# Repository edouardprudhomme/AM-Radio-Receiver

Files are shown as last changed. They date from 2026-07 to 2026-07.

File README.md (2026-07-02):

# AM Radio Receiver




A fully functional, custom-built AM Radio Receiver designed from scratch on a breadboard. This project blends electronic design with electromagnetic field theory to successfully capture local AM broadcasting frequencies (540 kHz to 1600 kHz). 

Designed with a special **Montreal Canadiens (Bleu, Blanc, Rouge)** theme, the ultimate goal of this build was to achieve a clean signal at **TSN 690 kHz** to listen to live hockey broadcasts.

## 👥 The Team
* Edouard Prud'Homme
* Frédéric Pimentel

## 🎥 Video Explanation and Demonstration
*(https://www.youtube.com/watch?v=ummKtrk6xlA)* (in french)

## 🧠 Theoretical Operation (The 4 Stages)
1. **Reception (Faraday's Law):** A custom 40x40 cm wooden loop antenna captures variations in the ambient magnetic field, inducing an electromotive force.
2. **Tuning / Filtering (LC Circuit):** A parallel LC tank circuit isolates the target frequency. 
3. **Demodulation (Envelope Detector):** A Germanium diode with a low forward voltage drop rectifies the weak AM signal, stripping the high-frequency carrier wave.
4. **Amplification:** An LM386 audio amplifier IC boosts the isolated audio signal to drive standard headphones.

## 📐 Design Choices & Engineering Math
To hit our target of **TSN 690 kHz** reliably, we had to work within the strict constraint of our variable capacitor, which had a limited range of **10 pF to 100 pF**. 

* **Antenna Geometry:** We constructed a 40cm x 40cm wooden frame using brass screws (to avoid magnetic interference).
* **Inductance ($L$):** Winding exactly 20 turns of copper wire yielded a measured inductance of **~870 µH**.
* **Capacitance ($C$):** Using the resonance formula $f = \frac{1}{2\pi\sqrt{LC}}$, targeting 690 kHz required a capacitance of exactly **61 pF**. 

This brilliant mathematical alignment placed our target frequency directly in the center of our variable capacitor's range, allowing for highly stable and accurate tuning.

## 🛠️ Hardware & Tools
* **Antenna:** Custom wooden frame (40x40cm), 20 turns of copper wire, brass screws.
* **Tuning:** 10-100 pF Variable tuning capacitor.
* **Demodulation:** Germanium Diode.
* **Amplification:** LM386 Audio Amplifier IC.
* **Schematics:** Designed in [KiCad](https://www.kicad.org/).

## 📁 Repository Contents
* `/Hardware` - Contains the KiCad schematic (`.sch`) and project files.

## 🚀 How to Replicate
1. Open the `.sch` file in KiCad to view the complete wiring diagram.
2. Ensure the middle pin (rotor) of the variable capacitor is wired to common ground to eliminate "hand capacitance" interference while tuning.
3. Keep the breadboard wires as short as possible to reduce parasitic capacitance, which severely limits high-frequency reception (like CJAD 800 kHz).

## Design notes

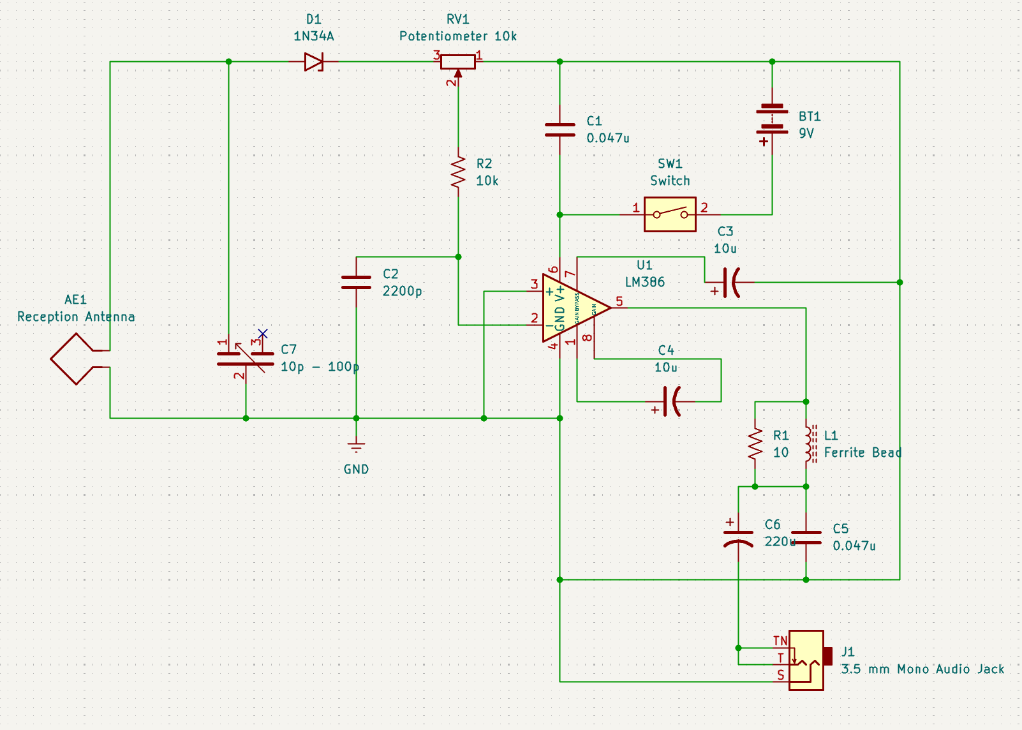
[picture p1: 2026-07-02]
Hardware/radio_schematic.png

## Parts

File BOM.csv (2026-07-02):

Reference | Quantity | Component | Description_Value | Notes
ANT1 | 1 | Cadre en bois | 40 cm x 40 cm | Structure pour la bobine de l'antenne
ANT2 | 1 | Fil verni | AWG 26 | Pour générer l'inductance de ~870 µH
ANT3 | 1 | Vis en laiton | Lot | Matériel de fixation non magnétique
C1 | 1 | Condensateur variable | 10 pF - 100 pF | Tuning pour le circuit LC (remplacement du modèle maison)
D1 | 1 | Diode au germanium | 1N34A | Détecteur d'enveloppe (démodulation)
U1 | 1 | Amplificateur opérationnel | LM386 | Amplificateur de puissance
R1 | 1 | Potentiomètre rotatif | 10 kΩ | Contrôle du volume
R2 | 1 | Résistance | 10 Ω | Filtre anti-oscillation
R3 | 1 | Résistance | 10 kΩ | Polarisation de l'ampli-op
C2 | 1 | Condensateur électrolytique | 220 µF | Couplage de sortie vers les écouteurs
C3 | 2 | Condensateur électrolytique | 10 µF | Gain de l'ampli-op et découplage
C4 | 2 | Condensateur en céramique | 0.047 µF | Filtre anti-oscillation et découplage
C5 | 1 | Condensateur en céramique | 2200 pF | Filtrage RF
L1 | 1 | Perle en ferrite | 998 Ω @ 100 MHz | Filtrage des hautes fréquences
SW1 | 1 | Interrupteur à glissière | 2 positions | On/Off du circuit
CON1 | 1 | Connecteur pour batterie | 9V | Alimentation
J1 | 1 | Prise audio stéréo | 3.5 mm | Sortie pour les écouteurs
BRD1 | 1 | Platine d'expérimentation | 4.5 x 3.5 cm | Base du prototype
WIR1 | 1 | Câbles de connexion | Ensemble de 15 | Câblage du circuit
PWR1 | 1 | Pile | 9V | Alimentation du circuit
OUT1 | 1 | Écouteurs | Faible impédance | Sortie audio
